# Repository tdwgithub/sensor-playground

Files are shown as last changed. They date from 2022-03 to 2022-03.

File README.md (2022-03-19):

# sensor-playground

Indoor Air-Quality Monitor / Sensor Playground Project

Copyright Notice

Copyright (c) 2022, tdwgithub
All rights reserved.

Redistribution and use in source and binary forms, with or without
modification, are permitted provided that the following conditions are met:
1. Redistributions of source code must retain the above copyright notice, this
   list of conditions and the following disclaimer.
2. Redistributions in binary form must reproduce the above copyright notice,
   this list of conditions and the following disclaimer in the documentation
   and/or other materials provided with the distribution.
THIS SOFTWARE IS PROVIDED BY THE COPYRIGHT HOLDERS AND CONTRIBUTORS "AS IS"
AND ANY EXPRESS OR IMPLIED WARRANTIES, INCLUDING, BUT NOT LIMITED TO, THE
IMPLIED WARRANTIES OF MERCHANTABILITY AND FITNESS FOR A PARTICULAR PURPOSE ARE
DISCLAIMED. IN NO EVENT SHALL THE COPYRIGHT HOLDER OR CONTRIBUTORS BE LIABLE
FOR ANY DIRECT, INDIRECT, INCIDENTAL, SPECIAL, EXEMPLARY, OR CONSEQUENTIAL
DAMAGES (INCLUDING, BUT NOT LIMITED TO, PROCUREMENT OF SUBSTITUTE GOODS OR
SERVICES; LOSS OF USE, DATA, OR PROFITS; OR BUSINESS INTERRUPTION) HOWEVER
CAUSED AND ON ANY THEORY OF LIABILITY, WHETHER IN CONTRACT, STRICT LIABILITY,
OR TORT (INCLUDING NEGLIGENCE OR OTHERWISE) ARISING IN ANY WAY OUT OF THE USE
OF THIS SOFTWARE, EVEN IF ADVISED OF THE POSSIBILITY OF SUCH DAMAGE.

INTRODUCTION

The Sensor Playground was designed to be a fun, easy-to-build platform for you
to experiment with software, sensors, displays, the IoT, etc.  It grew out of
a project I started after my wife suggested that some of the reasons for how
we had been feeling might be related to our indoor air-quality. 

It has been intentionally structured to make is straightforward for anyone 
with modest soldering skills and a bit of experience with tools like Arduino, 
to be able to construct a project that suits their ideas.

See: https://hackaday.io/project/182619-sensor-playground for more information.

It takes a kind-of "landing pad" approach, where you can build up the board 
and plug-in different kinds of processor modules, sensor sub-modules, displays,
etc. without the need to solder them directly to the board.  The number and 
variety of things you can plug in is virtually entirely up to you.

BUILDING YOUR OWN

There aren't a lot of "required" components, short of perhaps the power supply
section & the processor module and even that has been designed to give you a
wide range of choices.  

For example if you don't have a need for an encoder you don't need to install
it or its supporting pull-up resistors.  Same holds for the PCB-mount buttons.  As for
the sensors, I designed the PCB so that the processor I2C bus, SPI bus and a UART
are available via sockets or pins at a number of locations across the board.
This lets you connect the devices you choose at the points that make sense to
your particular application.  While there are outlines for some of the sensors
that I chose to use, these are by no means the ones you have to select.

3.3V, 5.0V & GND are made available on most connectors, so that it's easy to 
find a nearby power connection.

The component mounting types are all through-hole, making it pretty simple to
solder in what you want and there is a fair amount of space to get your soldering
iron into the places you need it to go.

SURFACE MOUNT COMPONENTS...! (relax, they're optional!)

I did add one (optional) surface-mount component: A processor reset controller.

If the processor module you choose doesn't already provide a power-on reset, or
perhaps its unreliable, then you can elect to install this component.  It's only
three pins and should be relatively easy for those with basic soldering skills and
a reasonably steady hand to install.  The only other component needed for the reset
circuit is a 100K, through-hole resistor.  See?  Not so hard after all!

PROCESSORS

I mentioned that you have flexibility in terms of your choice of processors.  This
is due to fact that the board has been designed to take one of two common processor
module types:

1. The ESP32 "DevKit"-style modules, from Esprssif, Inc.
2. A host of "Feather" form-factor modules.

The ESP32 modules are dual-core powerhouses, with WiFi, Bluetooth, large memory, etc.
If you have a processor-intensive application, the ESP32 is a great choice.

The "Feather" modules are a form-factor and pin-functionality specification created
by AdaFruit.  These modules are available with a wide range of processors, memory, 
IO, etc. and the pin-out is nearly identical across them all.  To date, I've used
ESP8266 Feather modules, ESP32 modules (same processor as the ESP32 DevKit, 
different form-factor), & ARM Cortex M0.  Given the circuit design I've chosen, 
all of these work on the Sensor Playground board.

I chose to focus on I2C, SPI and UART as the primary mechanism for connecting with the
sensors, displays, and other IO.  This allows for a wide range of devices to be 
connected, while limiting the amount of digital IO that would otherwise need to be
provided across the PCB.  There are a few  GPIO pins available on one of 
the headers (the same pins I use for the encoder and its button, along with the PCB-
mount push buttons).  

What if I want other IO than just SPI, I2C or UART?

Glad you asked!  If you elect to use a Feather form-factor processor module, you could
be in luck!  That specification also allows for the addition of "Feather Wing" expansion
modules to be plugged onto the top of Feather processor modules.  You can find a
pretty wide range of IO option boards that should satisfy a pretty wide range of requirements.

Alternatively, you could build something that uses SPI or I2C to drive an ADC or DAC.  That
would provide a nice means for gaining analog I/O and would allow the addition of 
non bus-based sensors.  I'm considering designing an add-on to do just that.

How do I build this thing?

I'll be adding some construction guides soon.  These will give you hints about how to go
about building the version of the Sensor Playground that best suits your application 
needs.

To find the construction guides, along with tips, etc., look in the "doc" folder at the
top level of this project.

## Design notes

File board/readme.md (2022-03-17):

Board Files

Copyright Notice

Copyright (c) 2022, tdwgithub
All rights reserved.

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

INTRODUCTION

The board schematic and PCB layout were created using KiCad V5.1.x.

Since the project design targets being a "landing pad" for various add-ons
like sensor boards, displays, etc., the schematic doesn't call out or 
include any specific sensor, etc.  This implies that the bill of materials
doesn't specify them either.  Rather, the schematic calls out the contact
points that I've made available (via 0.0" header pins or sockets).  With 
regard to the BOM, I will add elements to the BOM for the sensors and 
displays that I chose for my own application(s).

PCB

The PCB has been designed as a 2-layer board, using through-hole components
wherever possible (there are only a few potential exceptions).  The bottom of
the board floods the unused space with a ground plane, to help avoid noise or
ground-path issues.  If you choose to modify the PCB layout, I recommend that 
you remove the ground plane flood first, do you mods, then re-flood.  Also
remember that there are multiple connection points to that plane and so you want
to be sure those connections are maintained to it.  If you intend to remove the 
ground flood, you must re-create the GND connections that originally used it.

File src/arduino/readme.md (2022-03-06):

Example Arduino sketches.

Copyright Notice

Copyright (c) 2022, tdwgithub
All rights reserved.

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

Introduction 

The samples here demonstrate various features of the Sensor Playground.  They
aren't written as "final" applications, per se.  You'll note that I've tried
to keep the code fairly straightforward, not doing much of the Computer-Sciency
stuff I'm typically tempted to do.  The idea is to understand how to use the
features of the board, not to offer an off-the-rack application solution.

Arduino Libraries

I didn't provide the various 3rd-party libraries that I use in my sketches.
If I were to do that, I'd probably be violating a ton of copyrights, plus I'd
just end up duplicating the instructions for their use that the authors have
already provided.  

I do provide the source and libraries that *I'm* personally responsible for.
If you're not familiar with how to create your own libraries and how to use them
I'd suggest taking a look here: https://roboticsbackend.com/arduino-create-library/
and at other sources on the InterWebs.  

I've separated the Arduino example sketches from the support libraries I've written.
If you want to use the examples, you'll need to install those libraries into your
copy of the Arduino environment.

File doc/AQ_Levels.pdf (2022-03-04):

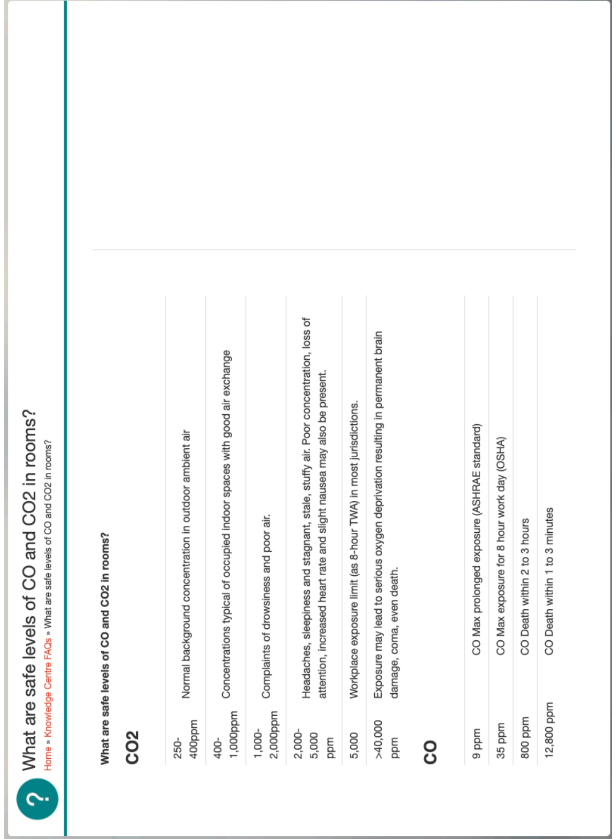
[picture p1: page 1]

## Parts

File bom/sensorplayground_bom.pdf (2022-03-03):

### sensorplayground_base

Id | Designator | Package | Quantity | Designation | Supplier and ref
1 | U3 | XCVR_2821 | 1 | 2821
2 | U1 | MODULE_ESP32-DEVKITC-32D | 1 | ESP32-DEVKITC-32D
3 | U5 | SOT-23 | 1 | MIC803-29D3VC3-TR
4 | RR1 | R_Axial_DIN0207_L6.3mm_D2.5mm_P10.16mm_Horizontal | 1 | R_US
5 | REF**,REF**,REF**,REF**,REF**,REF**,REF**,REF**,REF**,REF**,REF**,REF**,REF**,REF**,REF**,REF**,REF** | MountingHole_3.2mm_M3_DIN965 | 17 | MountingHole_3.2mm_M3_DIN965
6 | PP5,AF-MTU21D1,SJ2,SJ1,USB_Power1 | PinHeader_1x05_P2.54mm_Vertical | 5 | Conn_01x05_Male
7 | PP4,PP3,PP2,PP1 | PinHeader_1x02_P2.54mm_Vertical | 4 | Conn_01x02_Male
8 | F1 | Fuse_Littelfuse-LVR100 | 1 | Fuse
9 | REF**,REF**,REF**,REF**,REF**,REF**,REF**,REF** | MountingHole_3.2mm_M3_ISO7380_Pad | 8 | MountingHole_3.2mm_M3_ISO7380_Pad
10 | REF**,REF**,REF**,REF** | MountingHole_2.2mm_M2 | 4 | MountingHole_2.2mm_M2
11 | C4,C9,C8,C7,C6,C5,C3 | C_Disc_D5.0mm_W2.5mm_P5.00mm | 7 | .01uF
12 | ER3,ER2,ER1,RB2,RB1,R1 | R_Axial_DIN0207_L6.3mm_D2.5mm_P10.16mm_Horizontal | 6 | 10k
13 | GPIO_HDR1,SF-SGPx1,SF-SCD4x1 | PinHeader_1x04_P2.54mm_Vertical | 3 | Conn_01x04_Male
14 | ENC1 | RotaryEncoder_Alps_EC11E-Switch_Vertical_H20mm | 1 | Rotary_Encoder_Switch
15 | D1 | D_DO-41_SOD81_P10.16mm_Horizontal | 1 | 1N4007
16 | AF-OLED091 | PinHeader_1x08_P2.54mm_Vertical | 1 | Conn_01x08_Male
17 | PB2,PB1 | SW_PUSH_6mm | 2 | SW_Push_Dual_x2
18 | AF-PM25x1 | PinHeader_1x08_P2.54mm_Vertical | 1 | NC
19 | LED1 | LED_D5.0mm | 1 | LED
20 | PJ2 | PinHeader_1x03_P2.54mm_Vertical | 1 | Conn_01x03_Male
21 | C2,C1 | CP_Radial_Tantal_D4.5mm_P5.00mm | 2 | 33uF
22 | U2 | TO-220-3_Horizontal_TabDown | 1 | LM1117-3.3

1

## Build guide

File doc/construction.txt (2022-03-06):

Construction notes.

Copyright Notice

Copyright (c) 2022, tdwgithub
All rights reserved.

Redistribution and use in source and binary forms, with or without
modification, are permitted provided that the following conditions are met:
1. Redistributions of source code must retain the above copyright notice, this
   list of conditions and the following disclaimer.
2. Redistributions in binary form must reproduce the above copyright notice,
   this list of conditions and the following disclaimer in the documentation
   and/or other materials provided with the distribution.
THIS SOFTWARE IS PROVIDED BY THE COPYRIGHT HOLDERS AND CONTRIBUTORS "AS IS"
AND ANY EXPRESS OR IMPLIED WARRANTIES, INCLUDING, BUT NOT LIMITED TO, THE
IMPLIED WARRANTIES OF MERCHANTABILITY AND FITNESS FOR A PARTICULAR PURPOSE ARE
DISCLAIMED. IN NO EVENT SHALL THE COPYRIGHT HOLDER OR CONTRIBUTORS BE LIABLE
FOR ANY DIRECT, INDIRECT, INCIDENTAL, SPECIAL, EXEMPLARY, OR CONSEQUENTIAL
DAMAGES (INCLUDING, BUT NOT LIMITED TO, PROCUREMENT OF SUBSTITUTE GOODS OR
SERVICES; LOSS OF USE, DATA, OR PROFITS; OR BUSINESS INTERRUPTION) HOWEVER
CAUSED AND ON ANY THEORY OF LIABILITY, WHETHER IN CONTRACT, STRICT LIABILITY,
OR TORT (INCLUDING NEGLIGENCE OR OTHERWISE) ARISING IN ANY WAY OUT OF THE USE
OF THIS SOFTWARE, EVEN IF ADVISED OF THE POSSIBILITY OF SUCH DAMAGE.

Introducion

The minimum configuration you need for the Sensor Playground includes only:

1. The power-supply section.
2. The processor module section.

Everything else is your choice.  However, this document outlines some of the 
steps you'll need to take to pull off a successful build.

Power Supply

For this section, you will need the following components:

- D1 (1N4007 Diode).
- C1 (33uF Electrolytic Capacitor)
- U2 (LM1117-3.3) Three-terminal regulator
- C2 (33uF Electrolytic Capacitor)
- F1 (LittelFuse LVR100) (Optional)
- R1 (1K-ohm, 14/watt) Resistor.
- LED1 (Standard 5.0mm through-hole) LED
- USB_Power1 (DIYMall Micro-USB Power Adapter: https://www.amazon.com/gp/product/B07B5ZDLJY/ref=ppx_yo_dt_b_asin_title_o05_s00?ie=UTF8&psc=1)
- PJ2 (3-pin male header, optional)

1. You'll first need to solder the 5-pin header to the micro-USB power adapter.
   This header is included with the package.  Make sure to solder the side of
   the header that has the *shorter* pins into the power adapter board.
   
2. Insert the longer pins of the newly-built micro-USB power supply adapter into
   the Sensor Playground and solder.
   
3. Install D1 and solder.  Note the orientation.  The PCB shows a '+' & '-' symbol on
   either end of the outline.  Make sure to install the end of the diode that has the
   stripe into the '-' side.
   
4. If you want to use a fuse, insert that into the board where "Fuse" has been 
   labeled.  If you decide you don't need the fuse, you can use a piece of solid-core
   wire in its place.  Make sure the gauge is reasonable to avoid high resistance
   and potential heating/melting.
   
5. Insert C1 & C2 and solder.  Note that the footprints on the PCB are marked with
   '+' & '-' symbols.  When inserting the capacitors, make sure you orient them to
   the correct polarity!  Solder.
   
6. Insert the LED and solder.  Again, this is polarity-dependent. Typical through-hole
   LED's have one side that has been flattened.  That side is typically the negative.
   
7. Insert and solder R1 (1K Ohm, 1/4 watt through-hole).

8. If you want to have a convenient place to verify the 5V, 3.3V & GND of the PCB, you
   can install PJ2.  This is a simple 3-pin 0.1" make header.  Insert the side with the
   short pins and solder.

Processor

Generally speaking, in order to maintain as much flexibility as possible, I recommend 
that you use female sockets for the processor module(s).  This allows you to remove the
modules if needed (and there occasions where that is indeed necessary).  Depending on
the level of flexibility you need, you can choose to populate the sockets for both the
ESP32 DevKit modules and the Feather modules, or you can elect to populate only the 
sockets for the style you'll use.  

For either the ESP32 DevKit or the Feather modules, you'll need to install:

- C3 (0.1uF bypass capacitor)
- C4 (0.1uF bypass capacitor)

For the ESP32 DevKit modules, you will need:

- (2x) 0.1", 19-pin female socket header (DigiKey PN: ???)

Insert the sockets into each of the *outer* set of holes for U1 (you'll see labels at the 
bottom of the PCB with the text "ESP32" and just above that "Feather").  Solder each socket
header.

For Feather form-factor modules, you need:

- (1x) 0.1", 16-pin female socket header (DigiKey PN: ???)
- (1x) 0.1", 12-pin female socket header (DigiKey PN: ???)

Insert and solder the 12-pin female socket header into the *inner* set of holes on the left
side of the U1 footprint. Next, insert and solder the 16-pin female socket heaer into the 
*inner* set of holes on the right side of the U1 footprint.

As far was what I would describe as "required" components, that's about it. Of course,
if you want to *do* something with the board, you'll probably want to add a bit more to
it...

Encoder/Buttons

The rotary encoder and buttons provide a means for user input. With these and a display, you 
can createa pretty rich user experience.  The encoder itself has a button, so with the two
board-mount buttons, the encoder button and the encoder itself, you have a means to rotate
between options in a hierarchical menu system.

I'll provide example code to show how this can be accomplished.  If you do choose to install
the rotary encoder and buttons, here's what you need:

- (1x) ENC1 (Alps EC11E) Rotary Encoder
- (2x) PB1 & PB2 (6mm, PCB-mount pushbutton)
- (3x) ER1, ER2 & ER3 (10k ohm, 1/4-watt resistor)
- (2x) RB1 & RB2 (10k ohm, 1/4-watt resistor)
- (1x) 0.1" 4-pin make header. (optional)

You should probably install the puull-up resistors (ER1, ER2, ER3, RB1 & RB2) first, as these 
are the lowest profile components of this section. 

Once you've installed the oull-ups, install the push buttons.  These have 2 pins on either side
and it doesn't matter which way you choose to install them.  Insert and install both.

Finally, install the encoder.  It has 3 pins on one side and 2 on the other.  Orient the encoder
accordingly, then solder it in place.

If you have interest in accessing the IO lines that the encoder and buttons use, you can install
the 4-pin male header (see the list above).  Insert the side with the shorter pins into the PCB
and solder.

Of course, using the encoder and buttons probably makes most sense when used in conjunction with
a display.  That said, you don't have to.  As an example, you could choose to only install one 
or both of the PCB-mount buttons and use them to control your code *without* the need for a 
display.  Similarly, you could write your code to make use of the encoder, and not have a 
display.  It's totally up to you.  What was in my mind during the design was the combine the
display, buttons and encoder into a nice little menu-driven system.  To each his own... :-)

Everything Else

Before we get to the specifics, I want to make a few other points about how you can use things
on this board.

When it comes to all the connection points for the I2C/SPI/UART and Power, you get to choose 
whether you want to use:

- Solder your stuff directly, using the holes at those footprints.
- Use male, 0.1" header pins
- Use female, 0.1" header sockets.
- Something else (Not sure what, but you can if you'd like)

Those connection points are yours to use as you like.  Same goes for the mounting holes that
are scattered across the top 2/3 of the board.  

I designed the PCB to place the display(s) that I use in the upper-right of the PCB, but once
again, you don't need to use the connector up there (AF-OLED091) for that purpose.

I'm guessing you've realized by now that you can pretty much do what you choose on this board,
and get something running that you want.  Sorry to keep pounding on that point.

Ok, *now* Everything Else

From here on, what you choose to populate is even more specific to your application requirements.
In the center of the PCB, you'll find three footprints that provide access to the I2C:  
(SF-SCD4x1, SF-SGPx1, & AF-MTU21D1). The center footprint (AF-MTU21D1) is pinned-out slightly 
differently than the outer 2.  This was to allow me to plug in a few different sensor boards, 
whose connectors werent' pinned the same way.  However since you can set things up as you need to, 
this difference gives you a bit of added flexibilty when configuring your application.   In any case, 
the I2C lines, power and ground are common to each.

More toward the top of the PCB, you'll find another set of three 0.1" pin footprints (from left to
right: AF-PM25x1, SJ1 & SJ2).  SJ1 & Sj2 provide access to the SPI lines of the processor, with 2
different "enable" lines (no power available here, but just across from them are the I2C connectors
that have 3.3V & GND).  AFPM25x1 brings out a UART (Tx/Rx only), along with +5V & GND.

Inside the large rectangular outline at the top left of the PCB is another 5-pin footprint (PP5).
This simply provides another connection point for the +5V, +3.3V & GND buses.  

(INCOMPLETE)

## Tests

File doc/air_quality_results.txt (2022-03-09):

Indoor Air Quality: Some Results

As I've mentioned in other places, the reason I started this project was
due the fact that I was waking up at night feeling slightly ill, light-
headed, etc.  I noticed this even more during a period where I was sick; 
something just seemed "off".  During this time, my wife made the comment 
that she had often wondered about the quality of the air in our house.
Given her comment and what I was experiencing, I started into this project.

What did I find?

The first iteration (while still in breadboard form) included CO2 & VOC
sensors.  I had already connected it to Adafruit.IO and done a simple 
dashboard that let me watch the current sensor data, along with some
historical data.  When I woke up at night, I would grab my phone and take
a look.  I did this over several nights, since I was waking up frequently
anyway.  What I found during those nightly looks was that our CO2 levels
inside were nearly 2000ppm.  Since I had been reading about indoor air
quality, I knew that was too high, by a good bit in fact.

Indoor CO2 levels should ideally stay below 1000ppm. While this isn't a
dangerous level, at or above this level, many people start to feel kind
of dozy, sleepy, light-headed, etc. and these effects intensify as the 
levels increase.  In the recent years there has been an effort in 
public schools to monitor CO2 levels and based on the findings, modify
classroom behaviors in order to control the levels.  CO2 levels are 
very often tied to the efficiency of the building's air-handling 
systems (HVAC) and as you would expect, the more people there are in
a room, the more CO2 is being dumped into that room through simple
respiration.  If the air-handling system can't exchange stale indoor
air with fresh air quickly enough, CO2 levels can easily rise above
recommended levels.  The obvious (but not necessarily easy) thing to do
is to increase the rate of air exchanges in the space you want to control.
In the case of public schools, doing things like opening windows and doors
seems to be the main recommendation.  If the problems are significant, 
work on the HVAC system can be necessary.

See: "AQ_Levels.pdf" in this project folder for some interesting data about
CO2 & CO levels and their effects.

In my home, I first needed to determine what actions I could take that 
would materially impact the CO2 levels.  During one of my middle-of-the-
night "wake and check the air quality" sessions, it occured to me to try
to turn on the blower on our air-conditioner.  Since we have a Nest 
Thermostat and it has the ability to turn the blower on separately from
whether or not it is heating or cooling at the time, I just turned it on 
and started watching the CO2 levels.  The levels when I started were 
around 1800ppm and within about a half hour, they were just below 1000ppm.
As I was trolling around the Nest app, I found that it can schedule the
blower to run for some number of minutes within a time of day range. So,
I started to use that, initially setting time of the blower to be running
at 1/2 hour, each hour of the day.  That was intentionally aggressive
since I wasn't sure what would keep levels where I wanted them. Since
that time, I've been able to work out that running the blower for 
about 15 minutes each hour keeps the worst-case CO2 levels very near
1000ppm.  It peaks just prior the blower staring, then drops below
1000ppm and cycles like that.

Why does my house, with only 2 of us living here, allow CO2 levels to
get so high?  There's no single answer to that question, though there
are a few things to be aware of:

- Most homes are not built with specific facilities for controlling a 
  mix of outdoor & indoor air.  This was especiially true when the
  energy efficiency of houses wasn't considered an issue.  As a result,
  outdoor air coming into the house was the result of mechanical air
  movement inside the house, drawing outdoor air in throught the 
  numerous leaks the home presented.  Being air-tight just wasn't a
  consideration for older homes.  The result of this is that a large
  percentage of air that circulates in older homes (in particular) has
  been recirculated, with a relatively small percentage being sourced
  from outdoors.
  
- Our house was built around 1941-1942, with no notion of fresh-air
  intake in its HVAC design and when we moved in, was quite "leaky".
  We had older windows & doors and the insulation wasn't the best.
  Over time though, we've replaced all the doors, all the windows and
  have added more insulation.  The result is that the house has become
  more sealed.,,reducing its ability to bring fresh air into the space.
  
- We also don't keep houseplants.  It turns out that having plants around
  the house helps to reduce interior CO2.
  
What can you do to improve CO2 levels?

As I mentioned above, I was able to significantly impact the overall CO2 
levels in our home by simply scheduling our HVAC blower to run periodically.
I realize that's not possible for everyone, so here are a few tips I learned
while engaged in this project:

1.  When you can, open some windows or doors.
2.  Get some houseplants that are known to be good CO2 consumers:
    - Bird's Nest Fern
    - Snake Plant
    - Succulents & Cacti
    - Prayer Plants
    - See: https://balconygardenweb.com/most-effective-co2-absorbing-houseplants-proven-by-science/
      for some further suggestions.
3. Turn on your bathroom vent fans.  (It works, trust me.)
4. Add a fresh-air intake to your HVAC system.

What about other indoor air-quality readings?

In a typical home, Volatile Organic Compounds (VOC's) aren't usually too much
of a problem.  That said, individuals do react differently to different sources
of VOC's.  Think of things such as new carpeting.  You know that smell that 
permeates the house when you install new carpeting?  It's the result of VOC's.
New curtains?  VOC's.  Aerosols?  VOC's.  The sensors I've used can provide you
with an aggregate concentation level, but not levels of specific compounds. 
Nevertheless, you can see the effects of these (and other) sources of VOC's and
using that information, you can take steps to reduce them.

Another important air-quality metric for many is particulate-matter.  These 
are pollutants that are suspended in the air and they can cause various 
symptoms in different individuals.  Pollen, dust, smoke, etc. are all
particulate-matter sources.  By tracking the concentrations of these, you can
again work to remove the sources to reduce their presence in your home.  If
you use a PM2.5-type sensor, you should be able to see a correlation between
the outdoor air quality and your indoor conditions.  I regularly check the
US government's airnow.gov site.  If you provide it with your zipcode, it will
produce a display that shows the reported air-quality near your residence.  In
my own case, when airnow.gov reports a lower air quality value, my PM2.5
sensor typically reports an increased concentration.  

Note that one of the ways to improve CO2 that I mentioned can also have a 
negative impact on PM2.5, as opening windows & doors will tend to bring 
more particulate matter into your home.  If you build the Sensor Playground
and have both CO2 & PM2.5 sensors on it, you should be able to see how one
impacts the other. Your mileage may vary.

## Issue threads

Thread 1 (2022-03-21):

Feature: ESPHome

jrsphoto, 2022-03-21:
I am into home automation and  the system I use,[ Home Assistant](https://www.home-assistant.io/), has extensive support for something called [ESPHome](https://esphome.io/).  Home automation would be a great use for this board and all the sensor data can be stored, graphed, and utilized in almost limitless ways within the Home Assistant environment, and by using ESPHome, it might not be that hard to implement.

tdwgithub, 2022-03-21:
John,
One of the specific applications I had in mind for the SP was to control the HVAC a bit more, based on the sensor readings it provides.  I want to trigger ventilation when levels get too high and vice-versa as they come down.  
I've read a bit on Home Assistant but have never heard of ESPHome 'til now.  Very cool!  Going to read up on both and see how the SP could be integrated.  Thanks for the suggestions!
My current HA "system" consists of mainly lighting control, a NEST thermostat, sensors for temperature, humidity, VOC, & PM2.5 (the SP, of course), plus cameras, some water-ingress sensors, & my garage-door monitor.  They're not integrated via any particular management system though and with all that I've done, I think it's about time to do that.  That's why Home Assistant & ESPHome (or something like them) looks really interesting.
Thanks again!
Todd
    On Monday, March 21, 2022, 02:48:55 AM EDT, John Scherer ***@***.***> wrote:

I am into home automation and the system I use, Home Assistant, has extensive support for something called ESPHome. Home automation would be a great use for this board and all the sensor data can be stored, graphed, and utilized in almost limitless ways within the Home Assistant environment, and by using ESPHome, it might not be that hard to implement.

—
Reply to this email directly, view it on GitHub, or unsubscribe.
Triage notifications on the go with GitHub Mobile for iOS or Android.
You are receiving this because you are subscribed to this thread.Message ID: ***@***.***>

jrsphoto, 2022-03-25:
ESPHome is very cool and using it with home assistant is wonderful.  You can even do over-the-air updates to esp32's running ESPHome.  I use them to monitor my water heater (temp and when it comes on/off, etc.  bunch of other applications too.  Then log everything to a sql database and graph with Grafana.

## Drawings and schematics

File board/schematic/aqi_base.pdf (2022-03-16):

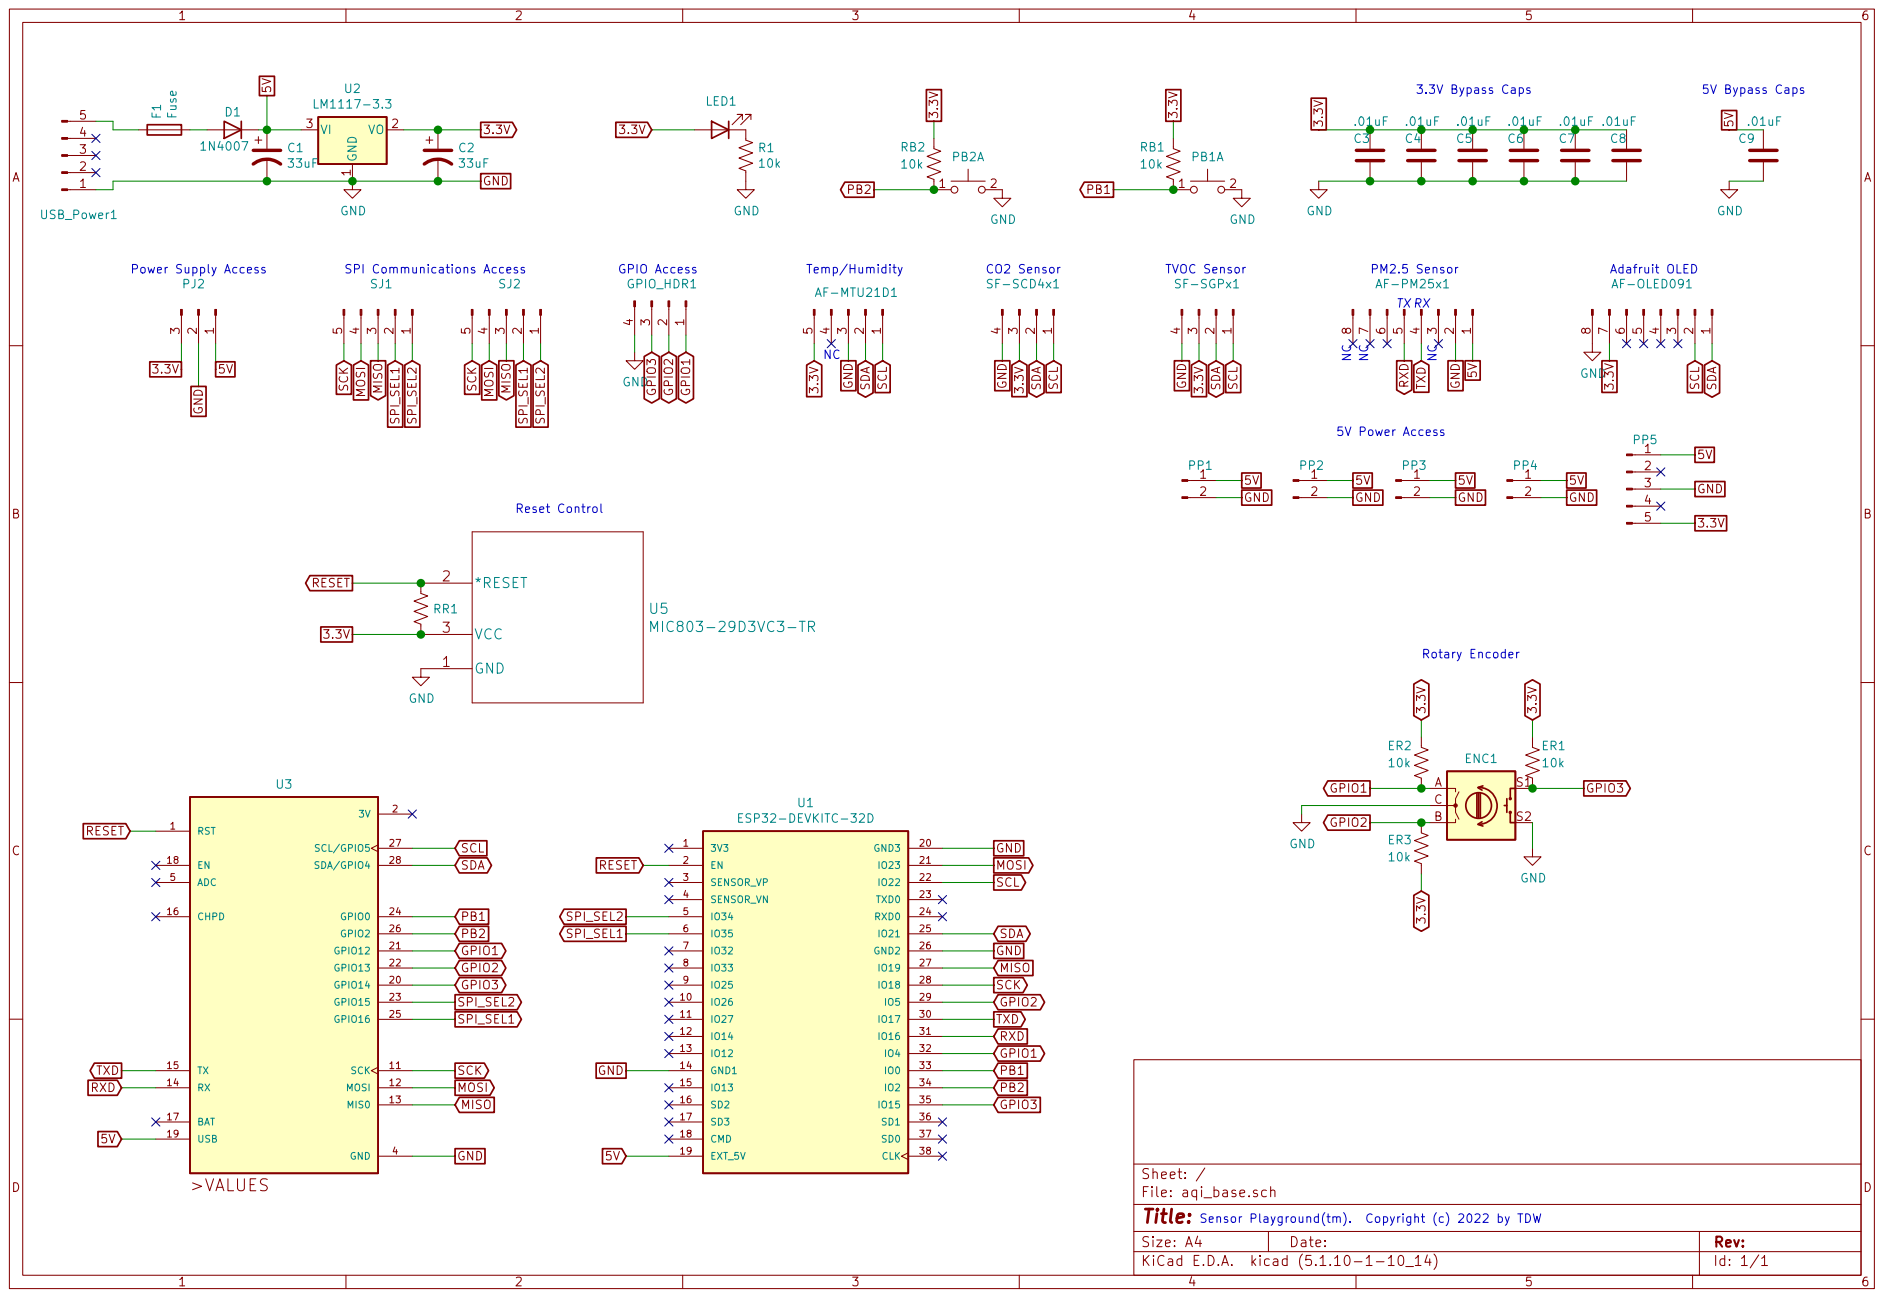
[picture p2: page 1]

Sensor Playground(tm). Copyright (c) 2022 by TDW

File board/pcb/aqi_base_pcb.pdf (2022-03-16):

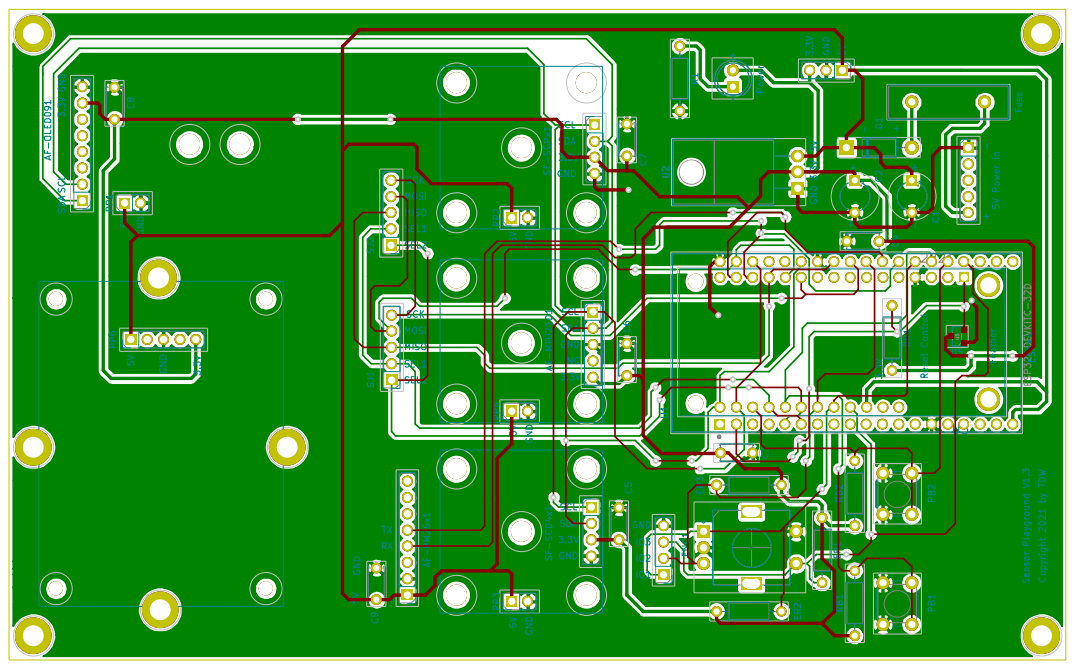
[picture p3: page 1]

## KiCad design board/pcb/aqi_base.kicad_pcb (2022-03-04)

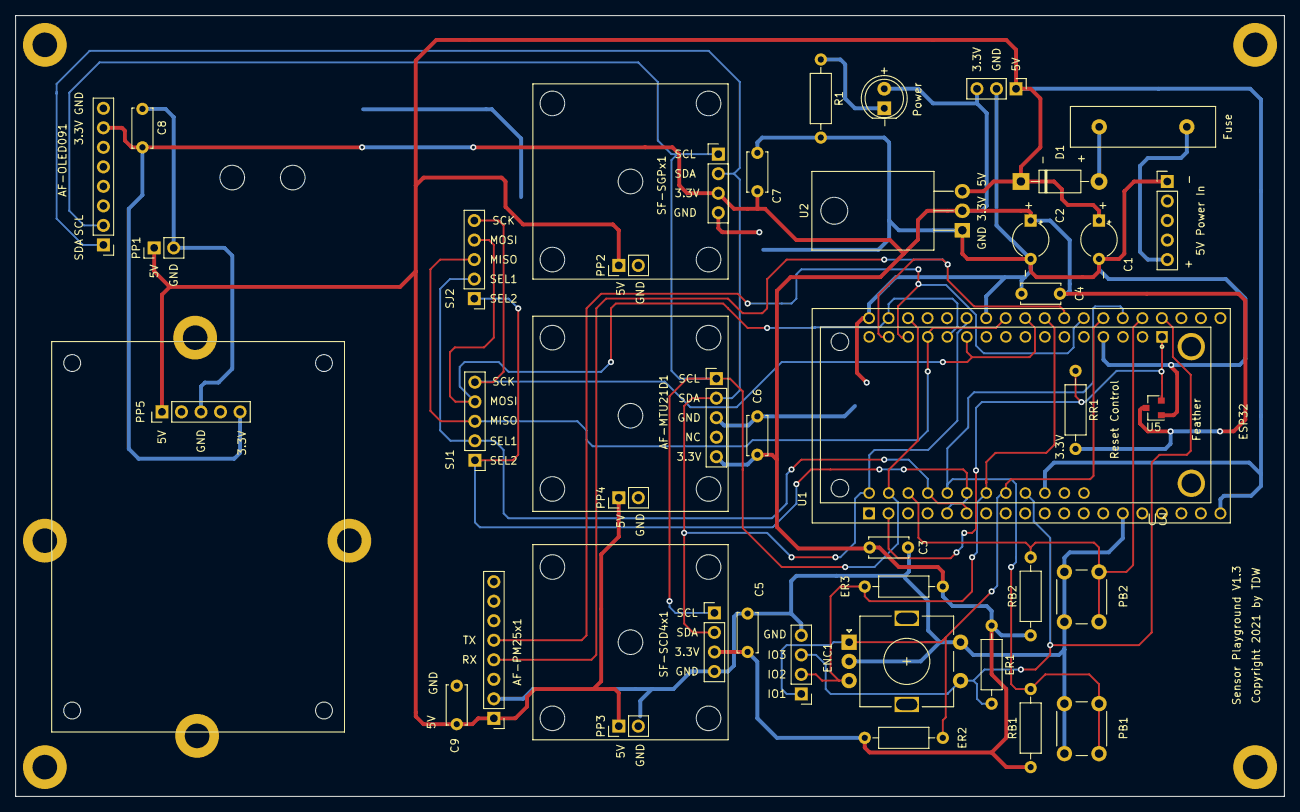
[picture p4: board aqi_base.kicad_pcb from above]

Board: 2 copper layers, 165.1 x 101.6 mm, 41 parts (0 on the bottom side), 21 nets.

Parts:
AF-MTU21D1: Conn_01x05_Male; PinHeader_1x05_P2.54mm_Vertical
AF-OLED091: Conn_01x08_Male; PinHeader_1x08_P2.54mm_Vertical
AF-PM25x1: NC; PinHeader_1x08_P2.54mm_Vertical
C1, C2: 33uF; CP_Radial_Tantal_D4.5mm_P5.00mm
C3, C4, C5, C6, C7, C8, C9: .01uF; C_Disc_D5.0mm_W2.5mm_P5.00mm
D1: 1N4007; D_DO-41_SOD81_P10.16mm_Horizontal
ENC1: Rotary_Encoder_Switch; RotaryEncoder_Alps_EC11E-Switch_Vertical_H20mm
ER1, ER2, ER3: 10k; R_Axial_DIN0207_L6.3mm_D2.5mm_P10.16mm_Horizontal
F1: Fuse; Fuse_Littelfuse-LVR100
GPIO_HDR1: Conn_01x04_Male; PinHeader_1x04_P2.54mm_Vertical
LED1: LED; LED_D5.0mm
PB1, PB2: SW_Push_Dual_x2; SW_PUSH_6mm
PJ2: Conn_01x03_Male; PinHeader_1x03_P2.54mm_Vertical
PP1, PP2, PP3, PP4: Conn_01x02_Male; PinHeader_1x02_P2.54mm_Vertical
PP5: Conn_01x05_Male; PinHeader_1x05_P2.54mm_Vertical
R1: 10k; R_Axial_DIN0207_L6.3mm_D2.5mm_P10.16mm_Horizontal
RB1, RB2: 10k; R_Axial_DIN0207_L6.3mm_D2.5mm_P10.16mm_Horizontal
RR1: R_US; R_Axial_DIN0207_L6.3mm_D2.5mm_P10.16mm_Horizontal
SF-SCD4x1: Conn_01x04_Male; PinHeader_1x04_P2.54mm_Vertical
SF-SGPx1: Conn_01x04_Male; PinHeader_1x04_P2.54mm_Vertical
SJ1, SJ2: Conn_01x05_Male; PinHeader_1x05_P2.54mm_Vertical
U1: ESP32-DEVKITC-32D; MODULE_ESP32-DEVKITC-32D
U2: LM1117-3.3; TO-220-3_Horizontal_TabDown
U3: 2821; XCVR_2821
U5: MIC803-29D3VC3-TR; SOT-23
USB_Power1: Conn_01x05_Male; PinHeader_1x05_P2.54mm_Vertical

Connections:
3.3V: AF-MTU21D1.5, AF-OLED091.7, C2.1, C3.1, C4.1, C5.1, C6.1, C7.1, C8.1, ER1.1, ER2.1, ER3.2, LED1.2, PJ2.3, PP5.5, RB1.1, RB2.1, RR1.2, SF-SCD4x1.3, SF-SGPx1.3, U2.2, U5.3
5V: AF-PM25x1.1, C1.1, C9.1, D1.1, PJ2.1, PP1.1, PP2.1, PP3.1, PP4.1, PP5.1, U1.19, U2.3, U3.19
GND: AF-MTU21D1.3, AF-OLED091.8, AF-PM25x1.2, C1.2, C2.2, C3.2, C4.2, C5.2, C6.2, C7.2, C8.2, C9.2, ENC1.C, ENC1.S2, GPIO_HDR1.4, PB1.2, PB2.2, PJ2.2, PP1.2, PP2.2, PP3.2, PP4.2, PP5.3, R1.2, SF-SCD4x1.4, SF-SGPx1.4, U1.14, U1.20, U1.26, U2.1, U3.4, U5.1, USB_Power1.1
GPIO1: ENC1.A, ER2.2, GPIO_HDR1.1, U1.32, U3.21
GPIO2: ENC1.B, ER3.1, GPIO_HDR1.2, U1.29, U3.22
GPIO3: ENC1.S1, ER1.2, GPIO_HDR1.3, U1.35, U3.20
MISO: SJ1.3, SJ2.3, U1.27, U3.13
MOSI: SJ1.4, SJ2.4, U1.21, U3.12
unnamed: D1.2, F1.2
unnamed: F1.1, USB_Power1.5
unnamed: LED1.1, R1.1
PB1: PB1.1, RB1.2, U1.33, U3.24
PB2: PB2.1, RB2.2, U1.34, U3.26
RESET: RR1.1, U1.2, U3.1, U5.2
RXD: AF-PM25x1.5, U1.31, U3.14
SCK: SJ1.5, SJ2.5, U1.28, U3.11
SCL: AF-MTU21D1.1, AF-OLED091.2, SF-SCD4x1.1, SF-SGPx1.1, U1.22, U3.27
SDA: AF-MTU21D1.2, AF-OLED091.1, SF-SCD4x1.2, SF-SGPx1.2, U1.25, U3.28
SPI_SEL1: SJ1.2, SJ2.2, U1.6, U3.25
SPI_SEL2: SJ1.1, SJ2.1, U1.5, U3.23
TXD: AF-PM25x1.4, U1.30, U3.15

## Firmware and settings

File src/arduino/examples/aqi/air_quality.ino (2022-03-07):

//$$$$$$$$$$$$$$$$$$$$$$$$$$$$$$$$$$$$$$$$$$$$$$$$$$$$$$$$$$$$$$$$$$$$$$$$$$$$$$$$$$$$$$$$$$$$$
//$$$$$$$$$$$$$$$$$$$$$$$$$$$$$$$$$$$$$$$$$$$$$$$$$$$$$$$$$$$$$$$$$$$$$$$$$$$$$$$$$$$$$$$$$$$$$
/*
Copyright (c) 2022, tdwgithub
All rights reserved.

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
1. Redistributions of source code must retain the above copyright notice, this
   list of conditions and the following disclaimer.

2. Redistributions in binary form must reproduce the above copyright notice,
   this list of conditions and the following disclaimer in the documentation
   and/or other materials provided with the distribution.

THIS SOFTWARE IS PROVIDED BY THE COPYRIGHT HOLDERS AND CONTRIBUTORS "AS IS"
AND ANY EXPRESS OR IMPLIED WARRANTIES, INCLUDING, BUT NOT LIMITED TO, THE
IMPLIED WARRANTIES OF MERCHANTABILITY AND FITNESS FOR A PARTICULAR PURPOSE ARE
DISCLAIMED. IN NO EVENT SHALL THE COPYRIGHT HOLDER OR CONTRIBUTORS BE LIABLE
FOR ANY DIRECT, INDIRECT, INCIDENTAL, SPECIAL, EXEMPLARY, OR CONSEQUENTIAL
DAMAGES (INCLUDING, BUT NOT LIMITED TO, PROCUREMENT OF SUBSTITUTE GOODS OR
SERVICES; LOSS OF USE, DATA, OR PROFITS; OR BUSINESS INTERRUPTION) HOWEVER
CAUSED AND ON ANY THEORY OF LIABILITY, WHETHER IN CONTRACT, STRICT LIABILITY,
OR TORT (INCLUDING NEGLIGENCE OR OTHERWISE) ARISING IN ANY WAY OUT OF THE USE
OF THIS SOFTWARE, EVEN IF ADVISED OF THE POSSIBILITY OF SUCH DAMAGE.
*/
//$$$$$$$$$$$$$$$$$$$$$$$$$$$$$$$$$$$$$$$$$$$$$$$$$$$$$$$$$$$$$$$$$$$$$$$$$$$$$$$$$$$$$$$$$$$$$
//$$$$$$$$$$$$$$$$$$$$$$$$$$$$$$$$$$$$$$$$$$$$$$$$$$$$$$$$$$$$$$$$$$$$$$$$$$$$$$$$$$$$$$$$$$$$$
/*
**  Air-Quality Monitor Demonstration Code. 
**  Copyright 2021,2022 by TDW
**  
**  Supports various processor modules, with and without
**  WiFi/Adaftuit IO support.
**  
**  Relies heavily on I2C devices/sensors.
** 
**  Example code only.  You mileage may vary.
*/
//$$$$$$$$$$$$$$$$$$$$$$$$$$$$$$$$$$$$$$$$$$$$$$$$$$$$$$$$$$$$$$$$$$$$$$$$$$$$$$$$$$$$$$$$$$$$$
//$$$$$$$$$$$$$$$$$$$$$$$$$$$$$$$$$$$$$$$$$$$$$$$$$$$$$$$$$$$$$$$$$$$$$$$$$$$$$$$$$$$$$$$$$$$$$

#include "credentials.h"

/*
 * Switches for enabling/disabling various features.
 */
#define USE_ADAFRUIT_IO             (1)
#define USE_PM25_SENSOR             (1)
#define USE_DISPLAY                 (1)
#define USE_SERIAL                  (0)
#define USE_PUSHOVER                (0)

/*
 * What processor module are we using?  Define
 * "CPU" to one of these (or add definitions for
 * cpu's you use.
 */
#define ESP8266                     (1)
#define ESP32S2                     (2)
#define ESP32S1                     (3)
#define CORTEX_M0                   (4)
#define CORTEX_M1                   (5)
#define CORECT_M4                   (6)

//
// Which CPU are we using from the above list?
//
#define CPU                         (ESP8266)
    
//
// If using the CO2 sensor, use altitude adjustment
//
#if (LOCATION==HOME)
    #define LOCATION_ALTITUDE                                ((uint16_t)365)
#elif (LOCATION==MOMDAD)
    #define LOCATION_ALTITUDE                                ((uint16_t)879)
#endif

// Header Includes
#include "SparkFun_SCD4x_Arduino_Library.h"
#include "SparkFun_SGP40_Arduino_Library.h"
#include "Adafruit_PM25AQI.h"
#include <Adafruit_GFX.h>
#include <Adafruit_SSD1306.h>
#include <math.h>
#include <HardwareSerial.h>
#include <Wire.h>

#if (USE_ADAFRUIT_IO==1)
    #include <AdafruitIO_MQTT.h>
    #include <AdafruitIO_Definitions.h>
    #include <AdafruitIO_Feed.h>
    #include <AdafruitIO_Time.h>
    #include <AdafruitIO_WiFi.h>
    #include <AdafruitIO.h>
    #include <AdafruitIO_Group.h>
    #include <AdafruitIO_Data.h>
    #include <AdafruitIO_Dashboard.h>
#else
    //
    // Spoofs the Adafruit.IO objects for controllers that don't
    // have WiFi or another way to reach the Internet.
    //
    #include "faux_io.h"    
#endif

#if (CPU==ESP8266)
    //#include <ESP8266WiFi.h>
#endif

//
// If USE_SERIAL is defined for a processor that only has a single
// UART, we undef the macro, so that that UART can be used for
// things like the PM2.5 sensor.  If your module has another UART,
// you can allow it to be used for console serial 
//
#if ( (CPU==ESP8266) || (CPU==ESP32S2) )
    #if (USE_PM25_SENSOR==1)
        #ifdef USE_SERIAL
            #undef USE_SERIAL
        #endif            
        #define USE_SERIAL          (0)
    #else
        #ifdef USE_SERIAL
            #undef USE_SERIAL
        #endif
        #define USE_SERIAL          (1)
    #endif
#else
    // OTHER CPU CONFIGURATION...
#endif

//
// Display Configurations
//
#define SCREEN_WIDTH 128 // OLED display width, in pixels
#define SCREEN_HEIGHT 64 // OLED display height, in pixels

//
// Declaration for an SSD1306 display connected to I2C (SDA, SCL pins)
// The pins for I2C are defined by the Wire-library. 
// On an arduino UNO:       A4(SDA), A5(SCL)
// On an arduino MEGA 2560: 20(SDA), 21(SCL)
// On an arduino LEONARDO:   2(SDA),  3(SCL), ...
//
#define OLED_RESET     -1 //4 // Reset pin # (or -1 if sharing Arduino reset pin)
#define SCREEN_ADDRESS 0x3D ///< See datasheet for Address; 0x3D for 128x64, 0x3C for 128x32
#if (USE_DISPLAY==1)
    Adafruit_SSD1306 display(SCREEN_WIDTH, SCREEN_HEIGHT, &Wire, OLED_RESET);
#endif    

//
// WiFi Configuration
//
const char                              *ssid           = NET_SSID;
const char                              *password       = NET_PW;

//
// PUSHOVER DEFINITIONS
//
#if (USE_PUSHOVER==1)
    // Token & Key for my account
    String                                  apitoken        = PUSHOVER_API_TOKEN;
    String                                  userkey         = PUSHOVER_USER;

    //
    // Wifi connection object for PUSHOVER
    //
    WiFiClient                              pushoverClient;
    const char                              pushoversite[]  = "api.pushover.net";
    char                                    pushoverMsg[128];
    WiFiClient                              client;
    int                                     length;
#endif    

//
// ADAFRUIT.IO Feed Names    
//
#define AIO_FEED_CO2                    ("CO2")
#define AIO_FEED_VOC                    ("VOC")
#define AIO_FEED_PM25                   ("PM2.5")
#define AIO_FEED_TEMPERATURE            ("House Temperature")
#define AIO_FEED_HUMIDITY               ("House Humidity")

//
// Primary Adafruit object
//
AdafruitIO_WiFi io(AIO_USERNAME, AIO_KEY, NET_SSID, NET_PW);

//
// Create the Adafruit.IO feed objects, using the names defined
// above.
//
AdafruitIO_Feed *temperature = io.feed(AIO_FEED_TEMPERATURE);
AdafruitIO_Feed *humidity = io.feed(AIO_FEED_HUMIDITY);
AdafruitIO_Feed *co2 = io.feed(AIO_FEED_CO2);
AdafruitIO_Feed *voc = io.feed(AIO_FEED_VOC);
AdafruitIO_Feed *pm25 = io.feed(AIO_FEED_PM25);

//
// Asynchronous timer management struct
//
typedef struct
{
    uint8_t                 running;
    uint32_t                capturedTicks;
}TM_TIMER_STRUCT;

//
// TIMER Functions Prototypes
//
static int TIMER_start(TM_TIMER_STRUCT *timer);
static int TIMER_finished(TM_TIMER_STRUCT *timer, unsigned long timeoutMS);
static int TIMER_cancel(TM_TIMER_STRUCT *timer);
static int TIMER_running(TM_TIMER_STRUCT *timer);
static float CtoF(float degreesCelsius);

// Prototype for pushover notification method
byte pushover(String pushovermessage);

// Adafruit.io update timer
static TM_TIMER_STRUCT                      adafruitUpdateTimer;
#define ADAFRUIT_UPDATE_TIMEOUT_MS          (10000)

// CO2 sensor read timer
static TM_TIMER_STRUCT                      co2UpdateTimer;
#define CO2_UPDATE_TIMEOUT_MS               (5000)

// VOC sensor read timer
static TM_TIMER_STRUCT                      vocUpdateTimer;
#define VOC_UPDATE_TIMEOUT_MS               (1000)

// OLED display update timer
static TM_TIMER_STRUCT                      oledUpdateTimer;
static TM_TIMER_STRUCT                      displayShiftTimer;
#define OLED_DISPLAY_SHIFT_TIMEOUT_MS       (5000)
#define OLED_UPDATE_TIMEOUT_MS              (250)
#define CLEAR_DISPLAY_TIMEOUT_MS            (2500)

// PM 2.5 sensor update timer
static TM_TIMER_STRUCT                      pmUpdateTimer;
#define PM_UPDATE_TIMEOUT_MS                (1000)

// Other methods
static void _startPMSensor(void);
static void _startVOCSensor(void);
static void _startCO2Sensor(void);
static void _sendStartupPushover(void);
static void _startAdafruitIO(void);
static void _startDisplay(void);
static void _bannerToDisplay(void);

//
// Sensor objects
//
SCD4x mySensor;
SGP40 vocSensor;
int displayState;

#if (USE_PM25_SENSOR==1)
    #if ( (CPU==ESP8266) || (CPU==ESP32S2) )
        #define pmSerial    Serial
    #else
        HardwareSerial  pmSerial(1);
    #endif
    Adafruit_PM25AQI aqiSensor = Adafruit_PM25AQI();
#endif    

// Which IO pins are the two discrete buttons connected?
#if (CPU==ESP32S2)
    #define LEFT_BUTTON_PIN             (9)
    #define RIGHT_BUTTON_PIN            (5)
#else
    #define LEFT_BUTTON_PIN             (0)
    #define RIGHT_BUTTON_PIN            (2)
#endif

// Which IO pins are the encoder inputs connected?
#if ( (CPU==ESP8266) || (CPU==ESP32S2) )
    #define ENCODER_UP_PIN          (12)
    #define ENCODER_DN_PIN          (13)
    #define ENCODER_BTN_PIN         (14)
#else
    #define ENCODER_UP_PIN          (4)
    #define ENCODER_DN_PIN          (5)
    #define ENCODER_BTN_PIN         (15)
#endif
    
/*
 * USE THESE MACROS TO CONTROL PRINTING TO THE CONSOLE!
 */
#if (USE_SERIAL==1)
    #define PRINT            Serial.print
    #define PRINTLN          Serial.println
    #define FLUSH            Serial.flush
#else
    #define PRINT(x)         
    #define PRINTLN(x)
    #define FLUSH()
#endif

//
// Flag controls whether or not to update the display
//
static int displayOK = 1;

//$$$$$$$$$$$$$$$$$$$$$$$$$$$$$$$$$$$$$$$$$$$$$$$$$$$$$$$$$$$$$$$$$$$$$$$$$$$$$$$$$$$$$$$$$$$$$
//$$$$$$$$$$$$$$$$$$$$$$$$$$$$$$$$$$$$$$$$$$$$$$$$$$$$$$$$$$$$$$$$$$$$$$$$$$$$$$$$$$$$$$$$$$$$$
//                                   APPLICATION CODE
//$$$$$$$$$$$$$$$$$$$$$$$$$$$$$$$$$$$$$$$$$$$$$$$$$$$$$$$$$$$$$$$$$$$$$$$$$$$$$$$$$$$$$$$$$$$$$
//$$$$$$$$$$$$$$$$$$$$$$$$$$$$$$$$$$$$$$$$$$$$$$$$$$$$$$$$$$$$$$$$$$$$$$$$$$$$$$$$$$$$$$$$$$$$$

/*! \fn
**
** FUNCTION: setup
**
** DESCRIPTION: Arduino initialization method.  Do any 
**              set up here that needs to be done prior to 
**              entering the main loop function of the application.
**
** PARAMETERS:
**
** RETURNS:
**
** COMMENTS:
**
*/
void setup() 
{    
    displayState = 0;

    // Get I2C configured
    Wire.begin();  

#if (USE_SERIAL==1)
    Serial.begin(9600);
    PRINTLN(F("Home Air-Quality Monitor."));
#endif

    //
    // Set up GPIO for buttons and encoder.
    //
    pinMode(LEFT_BUTTON_PIN, INPUT);
    pinMode(RIGHT_BUTTON_PIN, INPUT);
    pinMode(ENCODER_UP_PIN, INPUT);
    pinMode(ENCODER_DN_PIN, INPUT);
    pinMode(ENCODER_BTN_PIN,INPUT);

    //
    // Set up the display
    //
    _startDisplay();

    //
    // Connect to Adafruit.io
    //
    _startAdafruitIO();

    //
    // Send startup message via PUSHOVER
    //
    _sendStartupPushover();

    //
    // Set up the second UART & PM 2.5 sensor
    //
    _startPMSensor();            
    
    //
    // Start up the CO2 sensor
    //
    _startCO2Sensor();

    //
    // Start up the VOC sensor
    //
    _startVOCSensor();

    //
    // Final messages (on Serial and display)
    //
    PRINTLN("");
    PRINTLN("Starting sensor loop...");
    FLUSH();
    
    _bannerToDisplay();     
}

/*! \fn
**
** FUNCTION: loop
**
** DESCRIPTION: This method is called by the Arduino framework, as the primary application
**              loop.  Your goal is to do your work here and exit the function.  If you 
**              do anything that takes significant time, you'll need to put "yield()" calls
**              to keep the watchdog from resetting the device.
**
** PARAMETERS:
**
** RETURNS:
**
** COMMENTS:
**
*/
void loop() 
{
    static float           temp;
    static float           myHumidity;
    static uint16_t        CO2;
    static uint32_t        vocIndex;
#if (USE_PM25_SENSOR==1)    
    static PM25_AQI_Data   data;
#endif

    // If LEFT button pressed, display is enabled
    if (digitalRead(LEFT_BUTTON_PIN) == LOW)
    {
        displayOK = 1;        
        TIMER_start(&oledUpdateTimer);
    }

    // If right button is pressed, display is disabled
    if (digitalRead(RIGHT_BUTTON_PIN) == LOW)
    {
        displayOK = 0;
        displayState = 0;
        display.clearDisplay();
        display.display();
    }

    // Keep Adafruit IO refreshed
    io.run();

    // Time to read the PM2.5 Sensor
    if (TIMER_finished(&pmUpdateTimer, PM_UPDATE_TIMEOUT_MS))
    {
    #if (USE_PM25_SENSOR==1)
        if (aqiSensor.read(&data))        
        {        
            // Print concentations to the console.   
            PRINTLN("PM2.5 Readings:");
            PRINTLN();
            PRINTLN(F("---------------------------------------"));
            PRINTLN(F("Concentration Units (standard)"));
            PRINTLN(F("---------------------------------------"));
            PRINTLN(F("PM 1.0: ")); PRINT(data.pm10_standard);
            PRINT(F("\t\tPM 2.5: ")); PRINT(data.pm25_standard);
            PRINT(F("\t\tPM 10: ")); PRINTLN(data.pm100_standard);
            PRINTLN(F("Concentration Units (environmental)"));
            PRINTLN(F("---------------------------------------"));
            PRINT(F("PM 1.0: ")); PRINT(data.pm10_env);
            PRINT(F("\t\tPM 2.5: ")); PRINT(data.pm25_env);
            PRINT(F("\t\tPM 10: ")); PRINT(data.pm100_env);
            PRINTLN(F("---------------------------------------"));
            PRINT(F("Particles > 0.3um / 0.1L air:")); PRINTLN(data.particles_03um);
            PRINT(F("Particles > 0.5um / 0.1L air:")); PRINTLN(data.particles_05um);
            PRINT(F("Particles > 1.0um / 0.1L air:")); PRINTLN(data.particles_10um);
            PRINT(F("Particles > 2.5um / 0.1L air:")); PRINTLN(data.particles_25um);
            PRINT(F("Particles > 5.0um / 0.1L air:")); PRINTLN(data.particles_50um);
            PRINT(F("Particles > 10 um / 0.1L air:")); PRINTLN(data.particles_100um);
            PRINTLN(F("---------------------------------------"));
        
            // Do any math that we want for reporting to Adafruit IO
        }
        else
        {
            PRINTLN("Could not read from PM2.5 sensor!");    
        }
    #endif
    
        // Restart the read timer
        TIMER_start(&pmUpdateTimer);
    }

    // Time to read the VOCs?
    if (TIMER_finished(&vocUpdateTimer, VOC_UPDATE_TIMEOUT_MS))
    {
        vocIndex = vocSensor.getVOCindex();
        TIMER_start(&vocUpdateTimer);
    }

    // Time to read the CO2?
    if (TIMER_finished(&co2UpdateTimer, CO2_UPDATE_TIMEOUT_MS))
    {
        if (mySensor.readMeasurement()) // readMeasurement will return true when fresh data is available
        {
            CO2 = mySensor.getCO2();
            myHumidity = mySensor.getHumidity();    
            temp = mySensor.getTemperature();
        }
        
        TIMER_start(&co2UpdateTimer);
    }

#if (USE_DISPLAY==1)

    //
    // If the display was disabled by the pushbutton,
    // we continuously reset the display timer, so that
    // it will NOT display anything.
    //
    if (!displayOK)
        TIMER_start(&oledUpdateTimer);
        
    //
    // Time to update the OLED?  Since we can't display everyting
    // at one time on the OLED, we break it up into a couple of 
    // "screens", with different data on each, including a blank
    // screen to help extend the OLED lifetime a little.   
    //
    if (TIMER_finished(&oledUpdateTimer, OLED_UPDATE_TIMEOUT_MS))
    {
        display.setTextWrap(false);
        display.clearDisplay();        

        switch (displayState)
        {
            //
            // Display CO2, PM2.5 & VOC's on the OLED
            //
            case 0:
            {
                display.setCursor(0,0);             
                display.print("CO2: ");
                display.print(CO2);
                
                display.setCursor(0,18);
                display.print("VOC: ");
                display.print(vocIndex);          

            #if (USE_PM25_SENSOR==1)
                display.setCursor(0,36);             
                display.print(" PM: ");
                display.print(data.pm25_standard);
            #endif
            
                display.display();
    
                if (TIMER_finished(&displayShiftTimer, OLED_DISPLAY_SHIFT_TIMEOUT_MS))
                {
                    displayState = 1;
                    TIMER_start(&displayShiftTimer);
                }
            }
            break;
            
            //
            // Display TEMP and HUMIDITY on OLED
            //
            case 1:
            {    
                display.setCursor(0,0);
                display.print("TMP: ");
                display.print(CtoF(temp));

                display.setCursor(0,18);
                display.print("HUM: ");
                display.print(myHumidity);                
    
                display.display();
    
                //
                // We want to blank the display periodically, since this is an OLED.
                // and OLED's don't last forever.  So we blank it every sof often for
                // a bit, then move back to the top
                //
                if (TIMER_finished(&displayShiftTimer, OLED_DISPLAY_SHIFT_TIMEOUT_MS))
                {
                    displayState = 2;
                    TIMER_start(&displayShiftTimer);
                    display.clearDisplay();
                    display.display();                
                }
            }
            break;
            
            //
            // Blanking period expired?  Set up to display
            // state zero (CO2, PM2.5 & VOC's)
            //
            case 2:
            {            
                if (TIMER_finished(&displayShiftTimer, CLEAR_DISPLAY_TIMEOUT_MS))
                {
                    displayState = 0;
                    TIMER_start(&displayShiftTimer);
                }
            }
            break;
        }
                
        TIMER_start(&oledUpdateTimer);
    }
#endif

    // 
    // Time to update Cloud?
    //
    if (TIMER_finished(&adafruitUpdateTimer, ADAFRUIT_UPDATE_TIMEOUT_MS))
    {
        char            msg[128];
        PRINTLN();

        PRINT("VOC Index: ");
        PRINT(vocIndex);
        PRINTLN();                         

        // Serial monitor display         
        PRINT(F("CO2(ppm):"));
        PRINT(CO2);

        sprintf(msg, "\tTemperature(F): %f", CtoF(temp));
        PRINT(msg);

        sprintf(msg, "\tHumidity(%RH): %f", myHumidity);
        PRINT(msg);

        PRINTLN("");
        PRINTLN("Updating AdafruitIO...");

        FLUSH(); 
        
        temperature->save(CtoF(temp));
        humidity->save(myHumidity);

    #if (USE_PM25_SENSOR==1)
        pm25->save(data.pm25_standard);        
    #endif
        co2->save(CO2);
        voc->save(vocIndex);     
        
        TIMER_start(&adafruitUpdateTimer);
    }    
      
    yield();    
}

//$$$$$$$$$$$$$$$$$$$$$$$$$$$$$$$$$$$$$$$$$$$$$$$$$$$$$$$$$$$$$$$$$$$$$$$$$$$$$$$$$$$$$$$$$$$$$
//$$$$$$$$$$$$$$$$$$$$$$$$$$$$$$$$$$$$$$$$$$$$$$$$$$$$$$$$$$$$$$$$$$$$$$$$$$$$$$$$$$$$$$$$$$$$$
//                            STARTUP/INITIALIZATION FUNCTIONS
//$$$$$$$$$$$$$$$$$$$$$$$$$$$$$$$$$$$$$$$$$$$$$$$$$$$$$$$$$$$$$$$$$$$$$$$$$$$$$$$$$$$$$$$$$$$$$
//$$$$$$$$$$$$$$$$$$$$$$$$$$$$$$$$$$$$$$$$$$$$$$$$$$$$$$$$$$$$$$$$$$$$$$$$$$$$$$$$$$$$$$$$$$$$$

/*! \fn
**
** FUNCTION: _startPMSensor
**
** DESCRIPTION: Get the PM2.5 sensor set up and ready to use.
**
** PARAMETERS:
**
** RETURNS:
**
** COMMENTS:
**
*/
static void _startPMSensor(void)
{
#if (USE_PM25_SENSOR==1)        
    #if ( (CPU==ESP8266) || (CPU==ESP32S2) )
        pmSerial.begin(9600);
    #else
        pmSerial.begin(9600, SERIAL_8N1, 16, 17);
    #endif
    delay(1000);

    if (!aqiSensor.begin_UART(&pmSerial))
    {
        PRINTLN("Could not find PM 2.5 sensor!");
        while (1) {yield(); delay(1000);}
    }    
#endif    
    TIMER_start(&pmUpdateTimer);
}
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

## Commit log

2022-03-03 Initial BOM
    [sensorplayground_base.csv]
2022-03-04 Update to display missing reference designators
    [aqi_base.kicad_pcb]
2022-03-06 Adding the simple async timer class library.

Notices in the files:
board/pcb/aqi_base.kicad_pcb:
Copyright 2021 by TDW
